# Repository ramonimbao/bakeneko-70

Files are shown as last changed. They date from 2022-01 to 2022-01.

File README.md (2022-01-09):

# Bakeneko 70 V1

A 70% keyboard based on the Bakeneko 60 by kkatano.

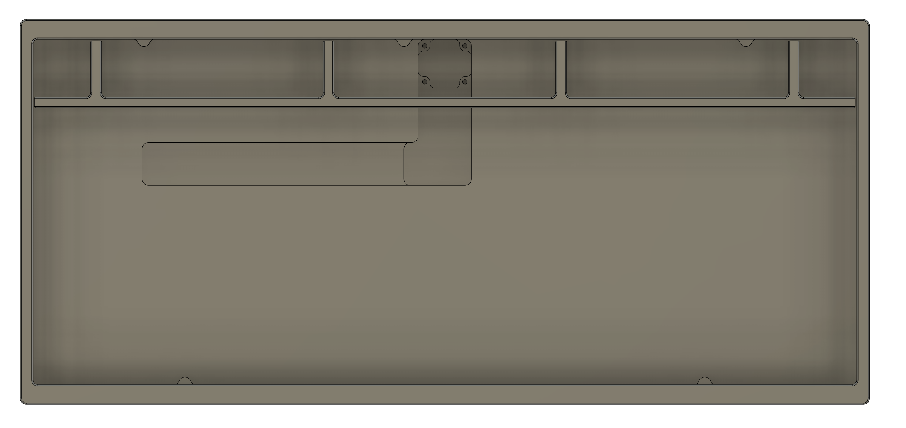
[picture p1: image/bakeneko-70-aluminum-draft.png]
Bakeneko 70


## Notes

Since this was based off of the Bakeneko 60, please take note that some files might still be named as bakeneko-60 or such. 

## Layouts

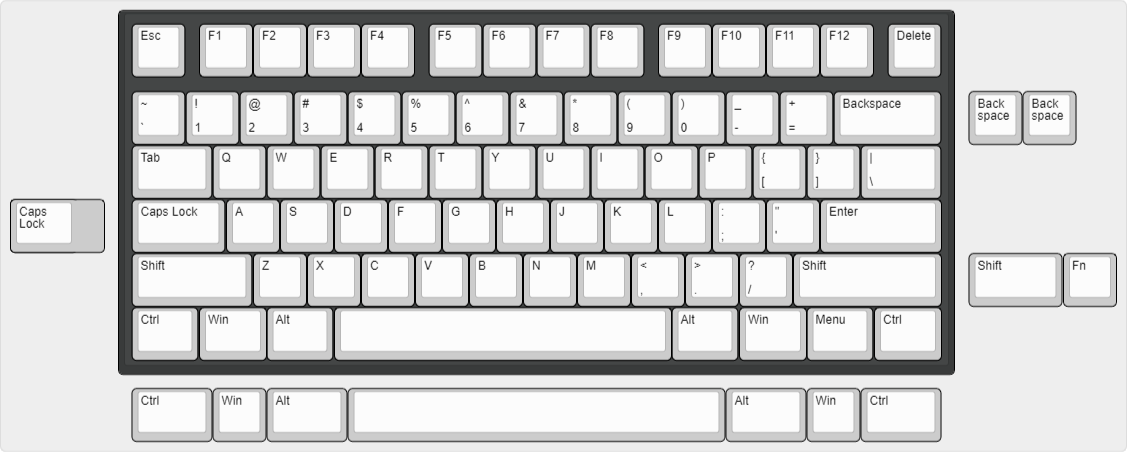
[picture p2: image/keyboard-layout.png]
Bakeneko 70 layouts


---

# Bakeneko 60 V3

A simple 60% keyboard for DIYers. This project is a special homage to TGR x Singa UNIKORN 60 and OTD 356 Mini.

## Features

- Single piece tray case
- O-ring gasket mount (Friction fit)
- USB-C with [Unified Daughterboard](https://github.com/ai03-2725/Unified-Daughterboard)
- QMK firmware and VIA ready
- Compatible with common 60% plates

## Specs

- Dimensions: 295 x 110 x 30mm
- Front height: 18.5mm
- Home row height: 31mm(with GMK keycaps and bumpons)
- Typing angle: 6 degree
- Weight:
  - PLA Case: 370g
  - Aluminum Case: 700g
- O-ring gasket: VMQ-50(Silicone 50 duro) AS568-262

## Notes

- All files are to be used at your own risk
- As for stabilizers, only PCB snap ins are supported
- This open source version is not compatible with CannonKeys' Bakeneko

## Resources

- Documents: https://drive.google.com/drive/folders/1tddSihOS8Pgf1lTQOjHohYCl8efxXIeH
  - Parts guide and other useful information
  - Will be added and updated as needed
- Discord: https://discord.gg/fMY96TeEwV
  - Have fun with community members
  - Talk about Bakeneko builds and mods, and share your works
  - You can also contact me from there

## Special thanks to

- **Elaine** for [Unikorn](https://geekhack.org/index.php?topic=98587.50). Allowed me to publish the Unikorn-inspired case as open source and encouraged me
- Of course, I also show my respect and gratitude to **yuktsi**
- **coarse** for PCB review and kind support. His great work has refined the PCB well

## Also I should mention

- **OTD** for 356 Mini. Origin of O-ring gasket mount style
- **Evy** for [Plain60 series](https://github.com/evyd13/plain60-c). I used it as a reference for my PCB design. They also answered my miscellaneous questions
- **ai03** for [MX_Alps_Hybrid](https://github.com/ai03-2725/MX_Alps_Hybrid) and [random-keyboard-parts.pretty](https://github.com/ai03-2725/random-keyboard-parts.pretty). Also got a lot of help from his discord server
- **overset** for [JP01](https://github.com/overset/JP01). The idea of publishing the case design on Onshape. After seeing their great work I switched from fusion360 to Onshape
- **Rhuk** gave me a lot of advice on keyboard design and manufacturing
- **Maker Keyboards** suggested adding a plate cutout to remove the PCB using a keycap puller
- And many community members for giving me advice and feedback, thanks!

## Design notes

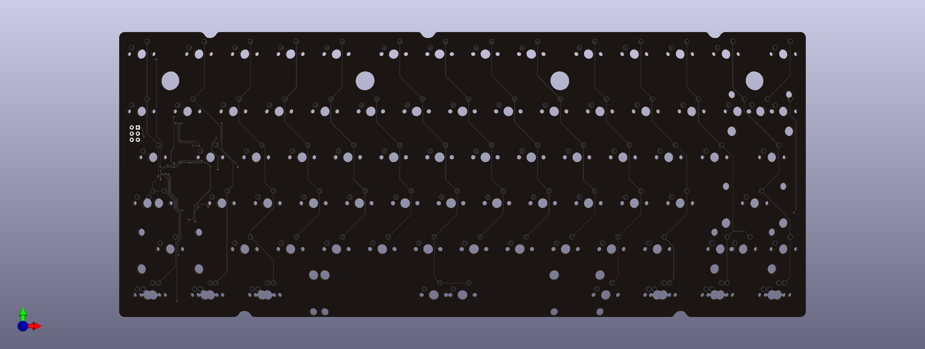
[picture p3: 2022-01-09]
image/bakeneko-70-pcb-top.png

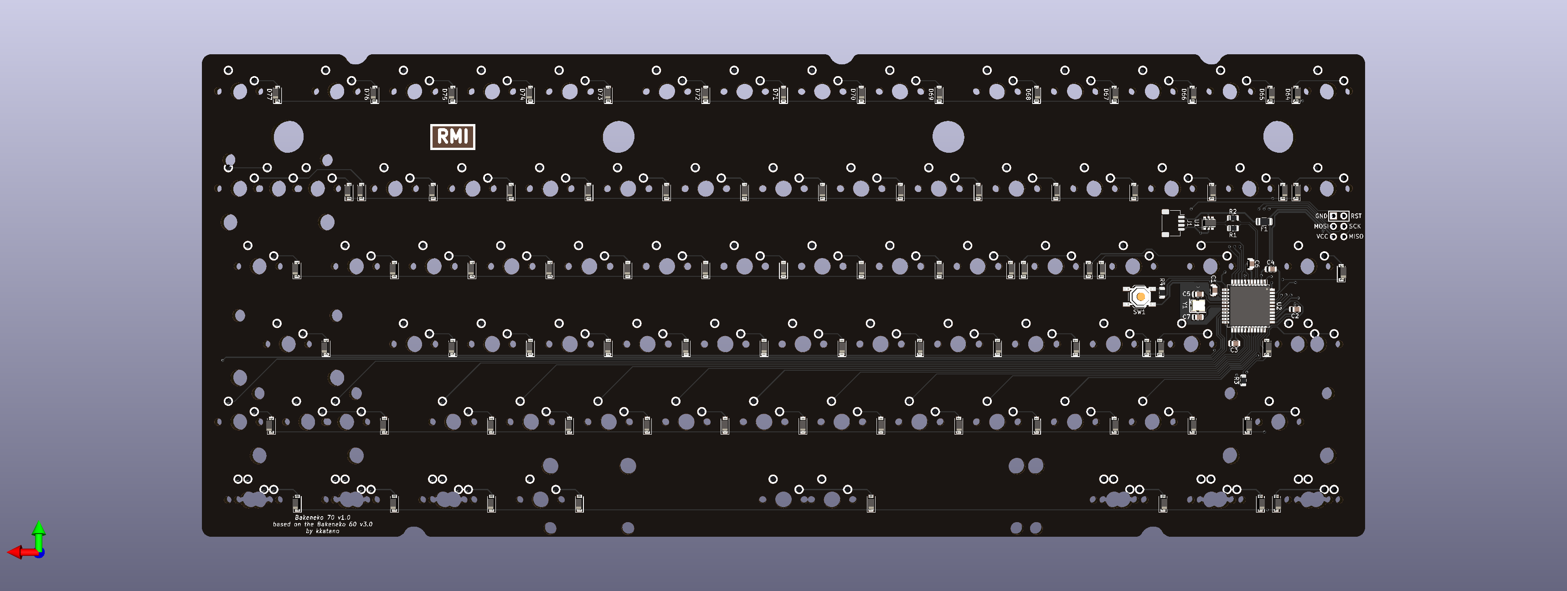
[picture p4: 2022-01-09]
image/bakeneko-70-pcb-bottom.png

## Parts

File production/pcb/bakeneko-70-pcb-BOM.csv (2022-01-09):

Comment | Designator | Footprint | LCSC
0.1u | C1,C2,C3 | Capacitor_SMD:C_0805_2012Metric
10u | C4 | Capacitor_SMD:C_0805_2012Metric
22p | C5,C7 | Capacitor_SMD:C_0805_2012Metric
1u | C6 | Capacitor_SMD:C_0805_2012Metric
1N4148 | D1,D2,D3,D4,D5,D6,D7,D8,D9,D10,D11,D12,D13,D14,D15,D16,D17,D18,D19,D20,D21,D22,D23,D24,D25,D26,D27,D28,D29,D30,D31,D32,D33,D34,D35,D36,D37,D38,D39,D40,D41,D42,D43,D44,D45,D46,D47,D48,D49,D50,D51,D52,D53,D54,D55,D56,D57,D58,D59,D60,D61,D62,D63,D64,D65,D66,D67,D68,D69,D70,D71,D72,D73,D74,D75,D76,D77 | Diode_SMD:D_SOD-123
500mA | F1 | Fuse:Fuse_1206_3216Metric
Signature | G1 | Ramon:Signature
JST SH 4-pin | J1 | Connector_JST:JST_SH_SM04B-SRSS-TB_1x04-1MP_P1.00mm_Horizontal
AVR-ISP-6 | J2 | random-keyboard-parts:Reset_Pretty
2u | MX16 | MX_Only:MXOnly-2U-NoLED
1.5u | MX17,MX30,MX67,MX69,MX71,MX73 | MX_Only:MXOnly-1.5U-NoLED
1.25u | MX31,MX59,MX60,MX61,MX63,MX64,MX65,MX66 | MX_Only:MXOnly-1.25U-NoLED
1.75u | MX32,MX56 | MX_Only:MXOnly-1.75U-NoLED
2.25u | MX44,MX45 | MX_Only:MXOnly-2.25U-NoLED
1u | MX1,MX2,MX3,MX4,MX5,MX6,MX7,MX8,MX9,MX10,MX11,MX12,MX13,MX14,MX15,MX18,MX19,MX20,MX21,MX22,MX23,MX24,MX25,MX26,MX27,MX28,MX29,MX33,MX34,MX35,MX36,MX37,MX38,MX39,MX40,MX41,MX42,MX43,MX46,MX47,MX48,MX49,MX50,MX51,MX52,MX53,MX54,MX55,MX57,MX68,MX72,MX74,MX75,MX76,MX77,MX78,MX79,MX80,MX81,MX82,MX83,MX84,MX85,MX86,MX87 | MX_Only:MXOnly-1U-NoLED
2.75u | MX58 | MX_Only:MXOnly-2.75U-NoLED
6.25u | MX62 | MX_Only:MXOnly-6.25U-ReversedStabilizers-NoLED
7u | MX70 | MX_Only:MXOnly-7U-ReversedStabilizers-NoLED
22 | R1,R2 | Resistor_SMD:R_0805_2012Metric
10k | R3,R4 | Resistor_SMD:R_0805_2012Metric
Reset | SW1 | Button_Switch_SMD:SW_SPST_TL3342
SRV05-4 | U1 | Package_TO_SOT_SMD:SOT-23-6
ATmega32U4-AU | U2 | Package_QFP:TQFP-44_10x10mm_P0.8mm
16MHz | Y1 | Crystal:Crystal_SMD_3225-4Pin_3.2x2.5mm

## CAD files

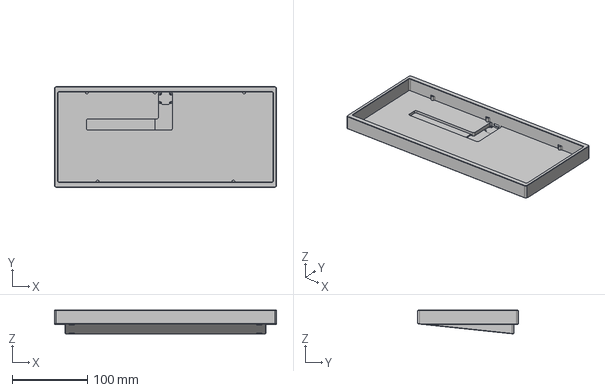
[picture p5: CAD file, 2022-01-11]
case/Case.step
295.7 x 134.0 x 31.9 mm

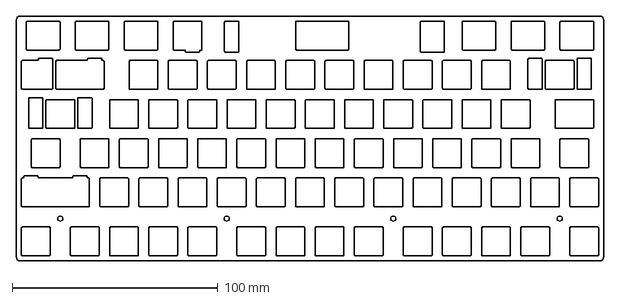
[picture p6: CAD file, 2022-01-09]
plate/bakeneko70-plate/bakeneko70-plate.dxf
285.8 x 119.1 mm

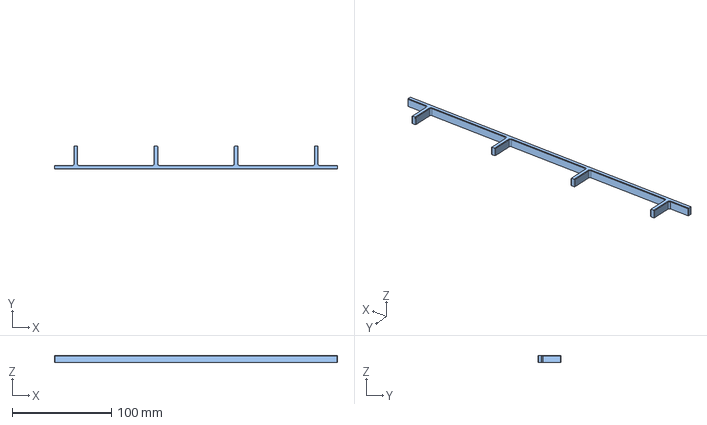
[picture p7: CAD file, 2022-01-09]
case/Blockers.step
285.8 x 23.3 x 7.00 mm

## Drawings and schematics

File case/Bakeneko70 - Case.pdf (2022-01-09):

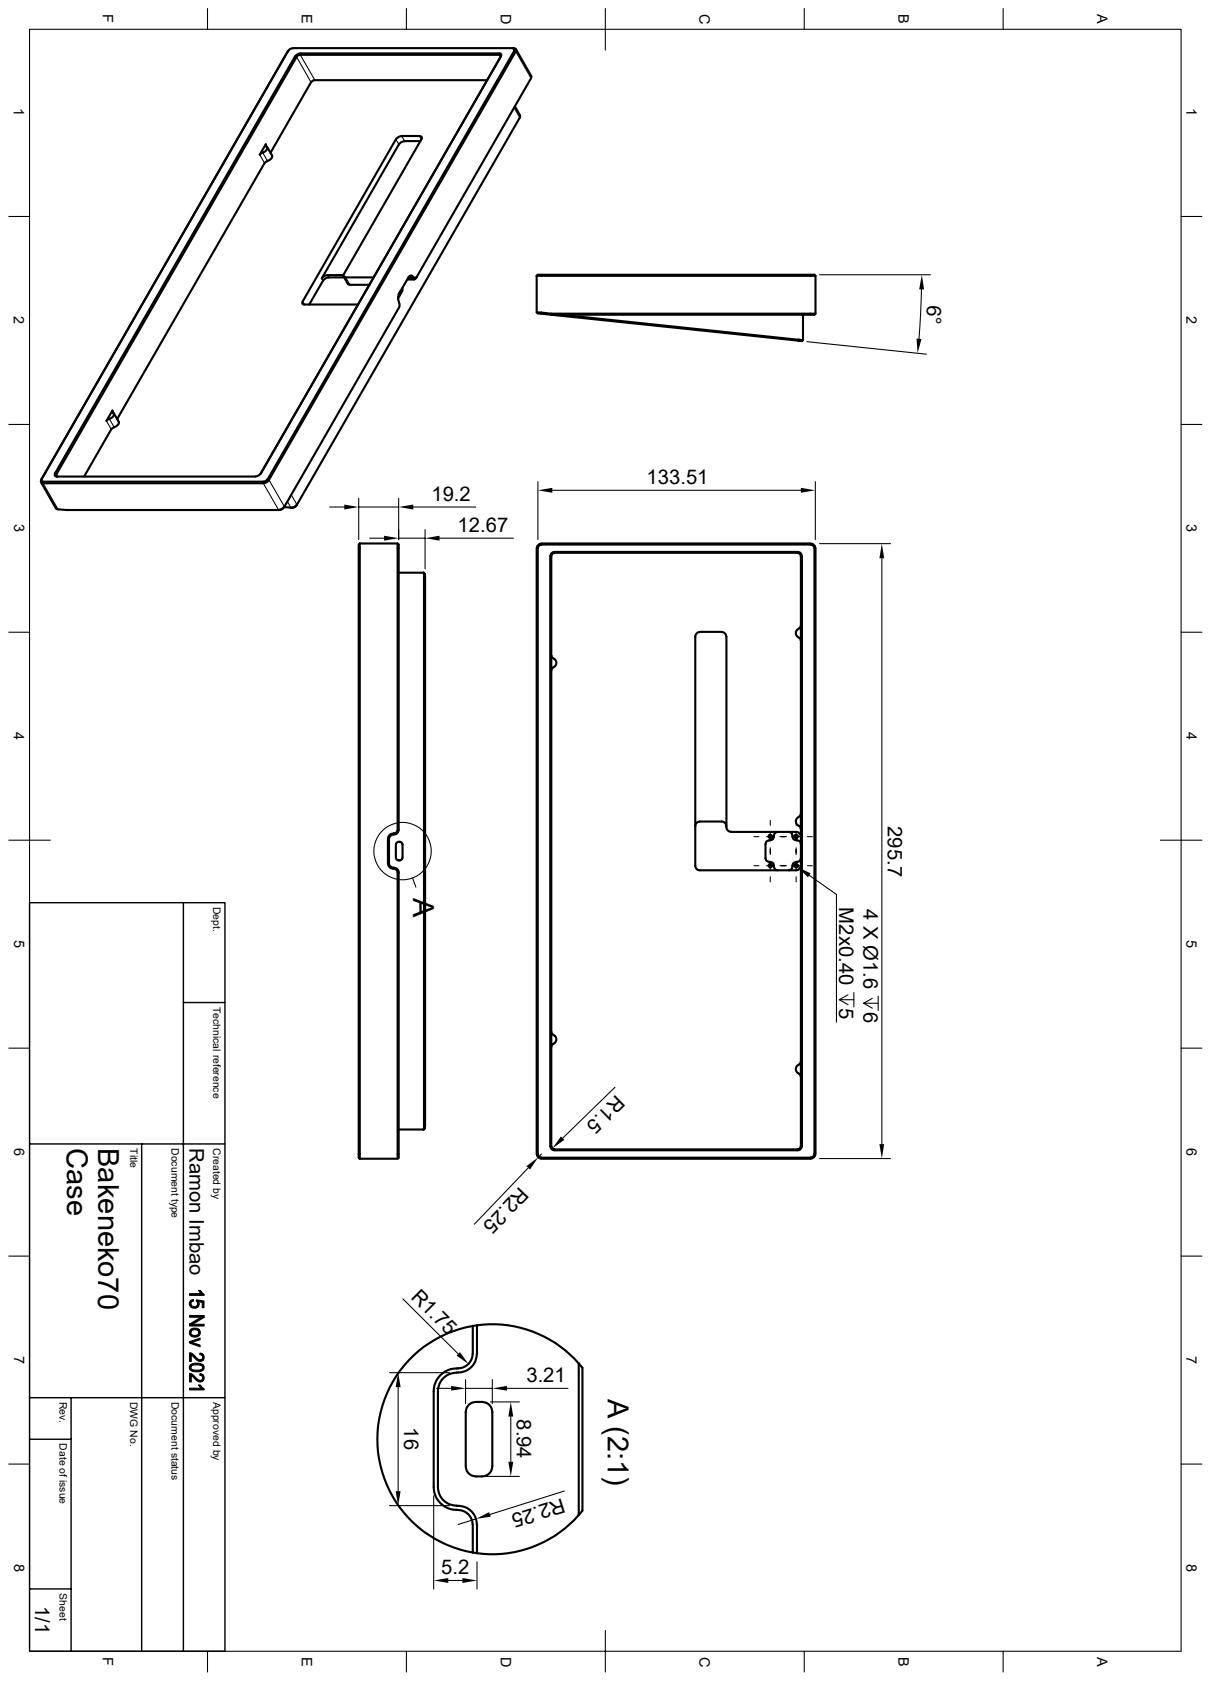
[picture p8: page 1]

1 A 2 3 4 5 6 7 8 1 2 3 4 5 6 7 8 FEDCB FEDCBA Dept. Technical reference Created by Approved by Title DWG No. Document type Document status Rev. Date of issue Sheet 1/1 Case Bakeneko70 Ramon Imbao 6° 295.7

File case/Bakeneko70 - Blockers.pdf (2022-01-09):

23.31 7

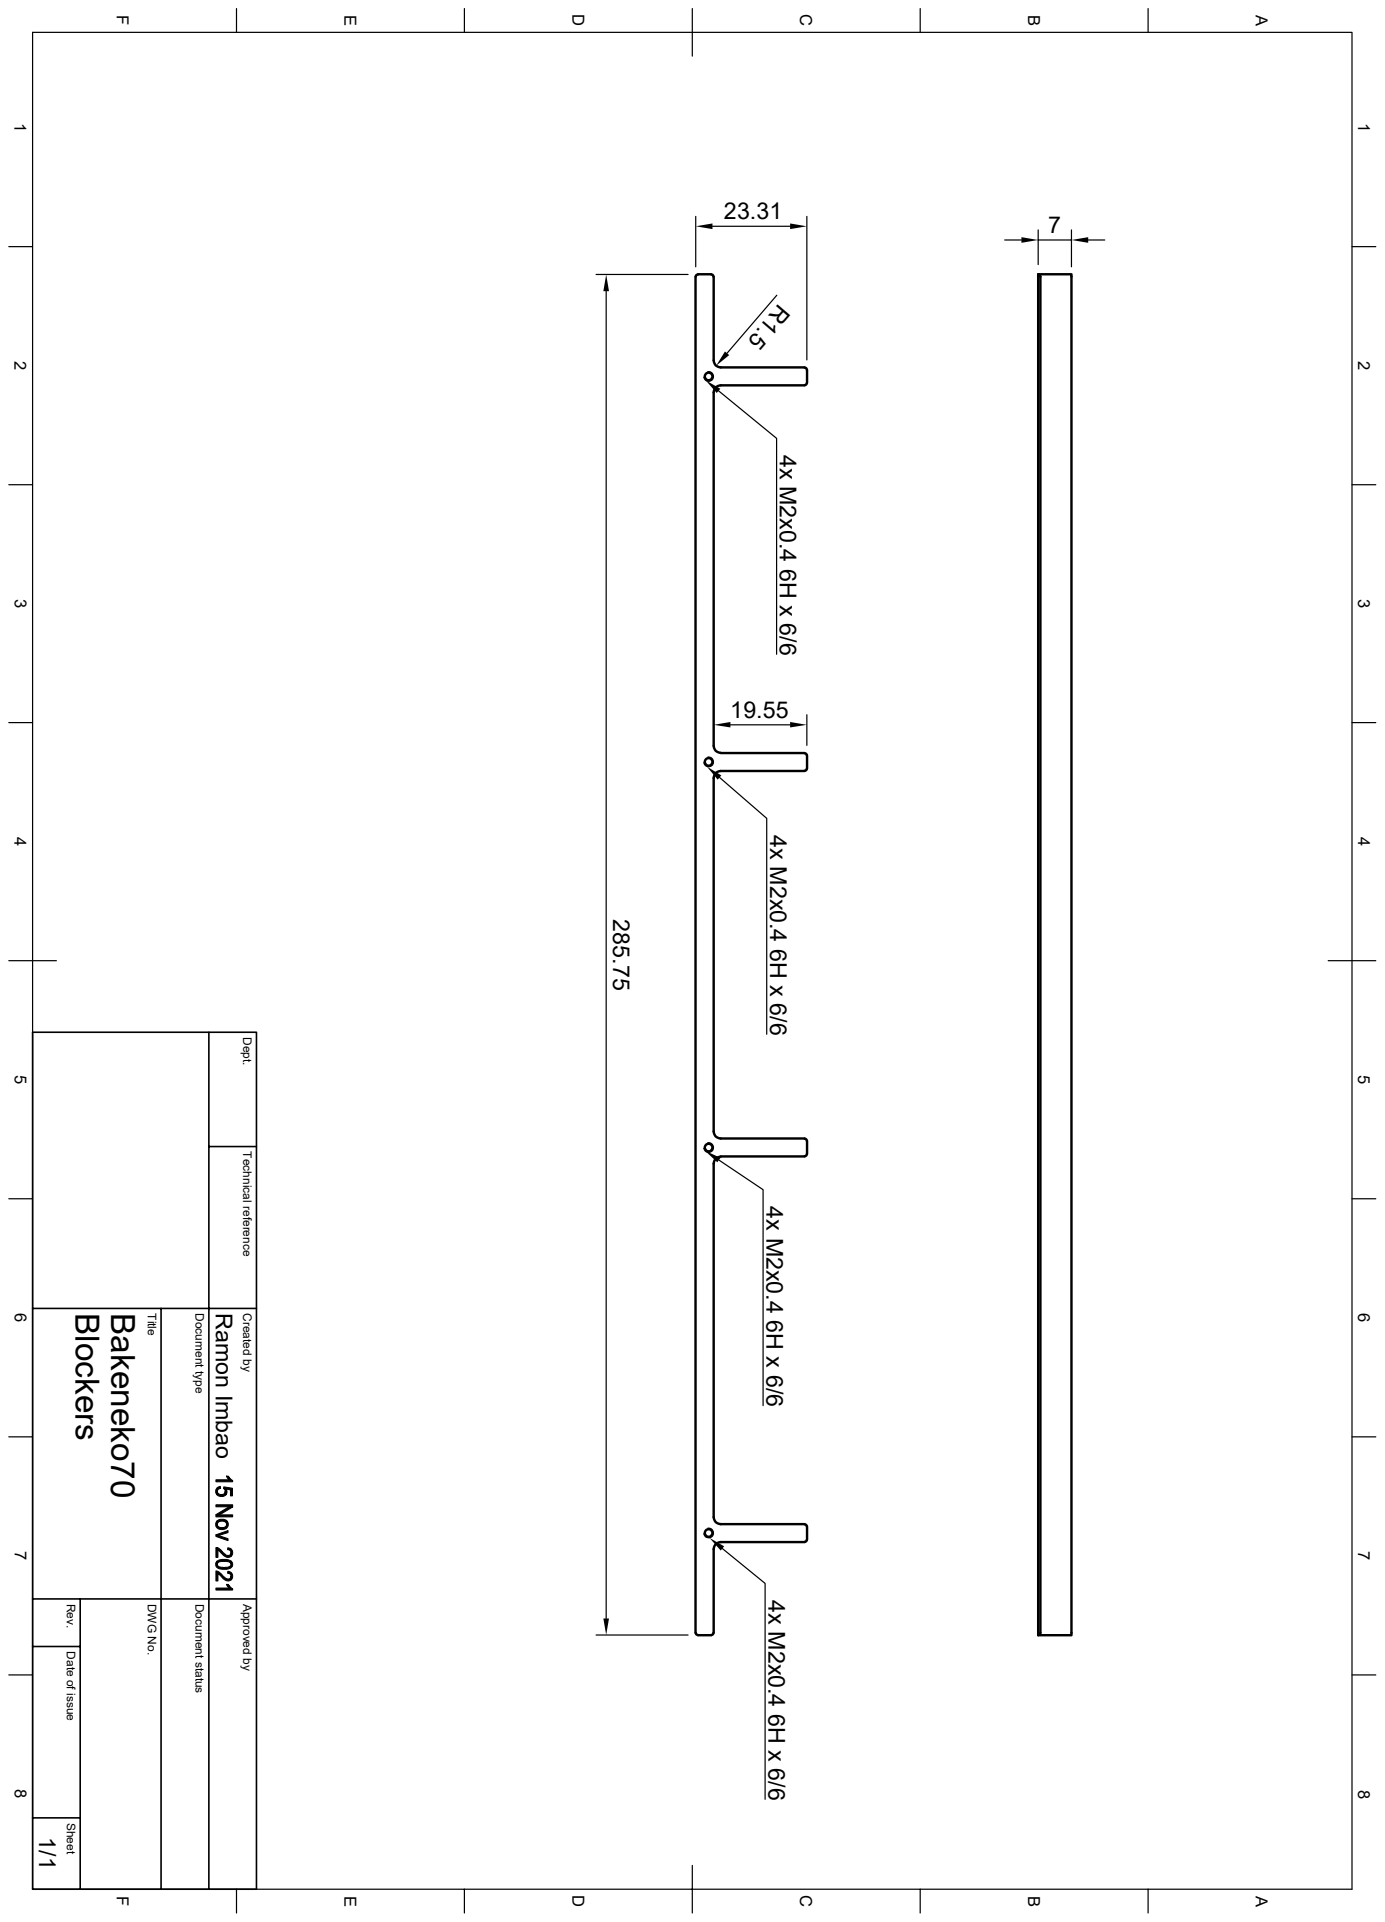
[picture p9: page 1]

1 A 2 3 4 5 6 7 8 1 2 3 4 5 6 7 8 FEDCB FEDCBA Dept. Technical reference Created by Approved by Title DWG No. Document type Document status Rev. Date of issue Sheet 1/1 Blockers Bakeneko70 Ramon Imbao 4x M2x0.4 6H x 6/6 4x M2x0.4 6H x 6/6 4x M2x0.4 6H x 6/6 4x M2x0.4 6H x 6/6 R1.5

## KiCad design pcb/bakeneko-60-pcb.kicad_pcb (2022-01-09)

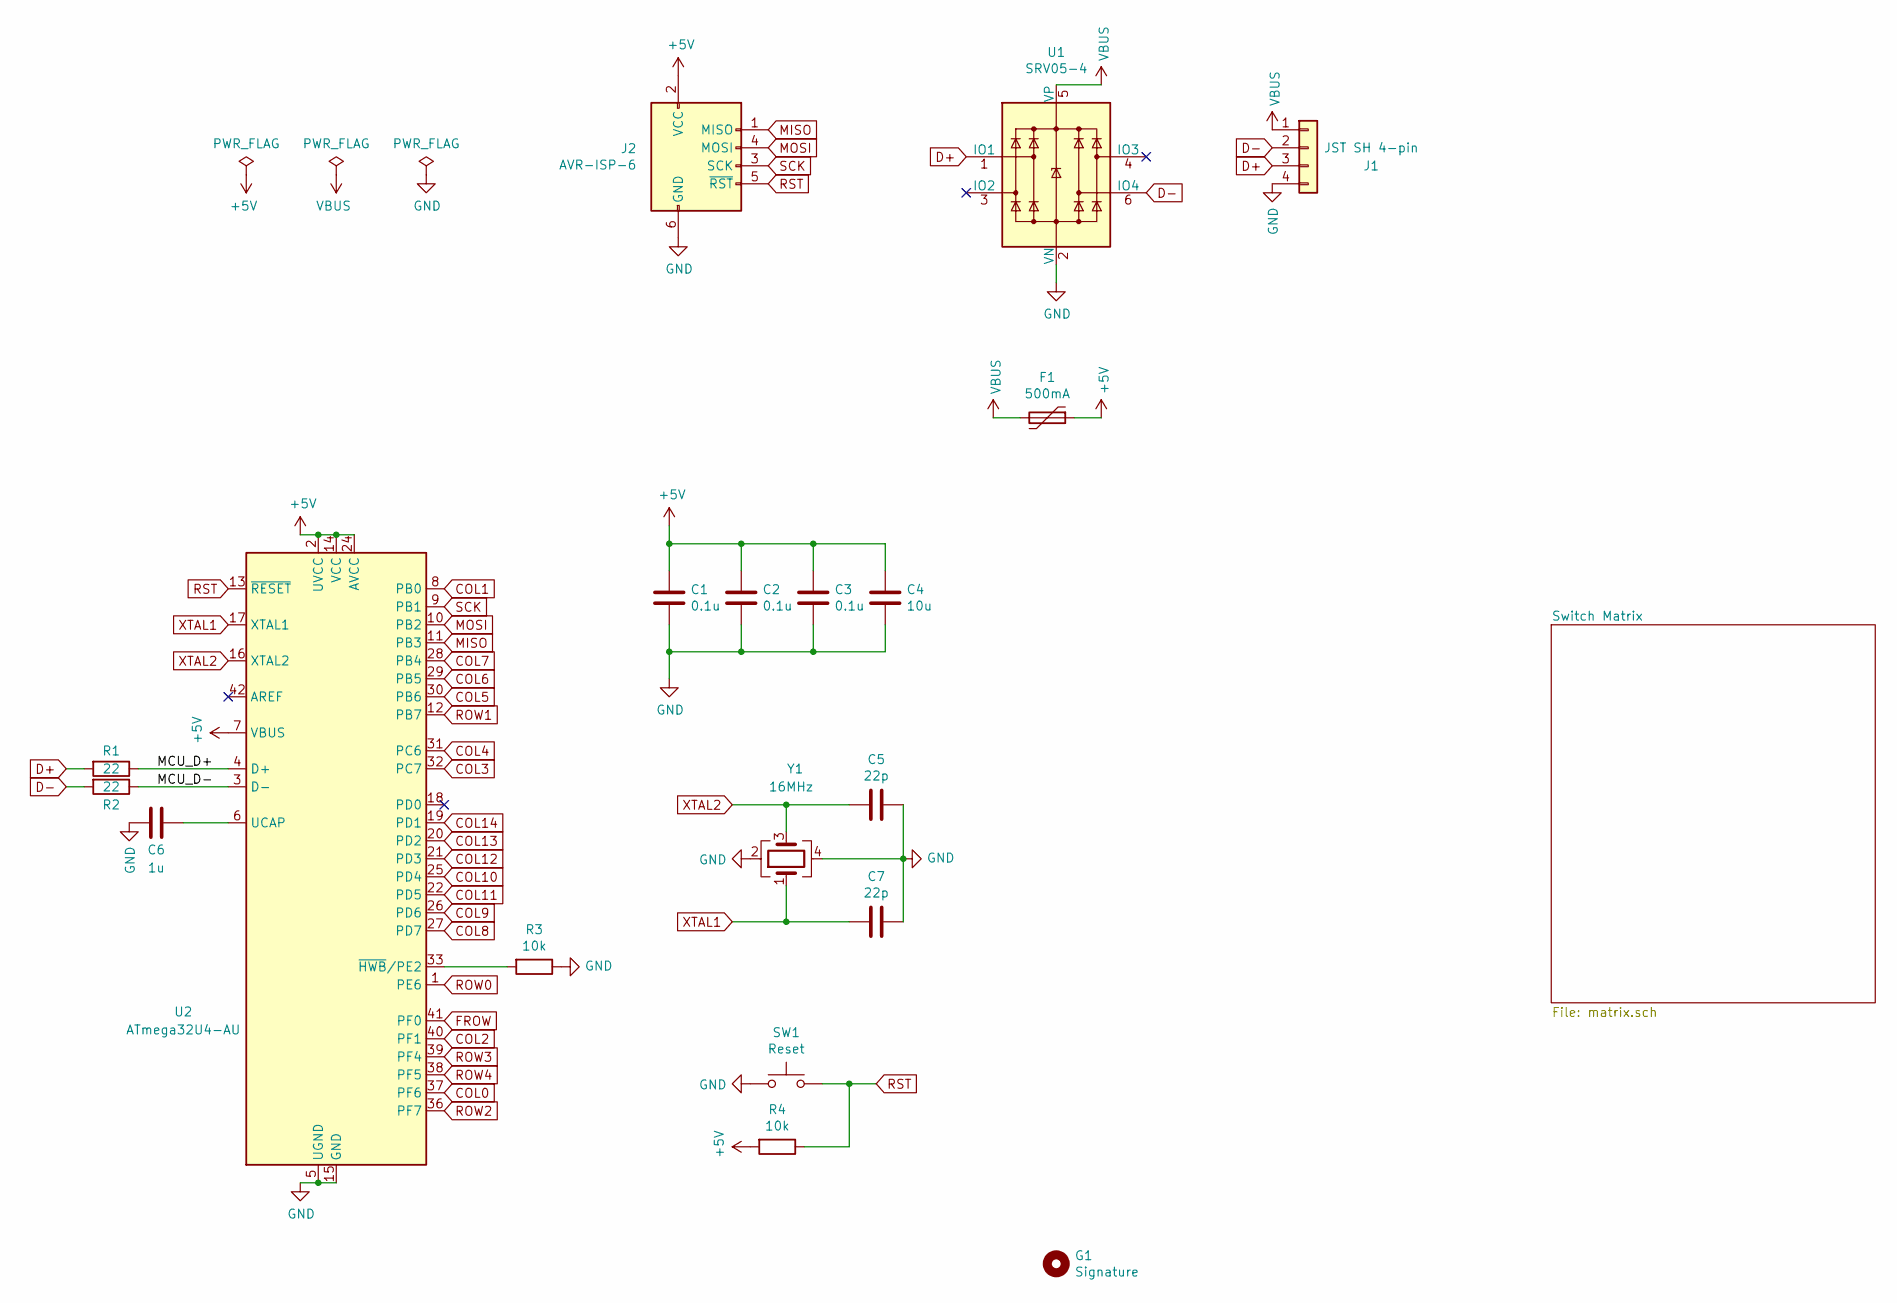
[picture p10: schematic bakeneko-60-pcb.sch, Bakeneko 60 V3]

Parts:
C1, C2, C3: 0.1u; C_0805_2012Metric; LCSC Part # C49678
C4: 10u; C_0805_2012Metric; LCSC Part # C15850
C5, C7: 22p; C_0805_2012Metric; LCSC Part # C1804
C6: 1u; C_0805_2012Metric; LCSC Part # C28323
F1: 500mA; Fuse_1206_3216Metric; LCSC Part # C70076
G1: Signature
J1: JST SH 4-pin; JST_SH_SM04B-SRSS-TB_1x04-1MP_P1.00mm_Horizontal; LCSC Part # C160404
J2: AVR-ISP-6; Reset_Pretty
R1, R2: 22; R_0805_2012Metric; LCSC Part # C17561
R3, R4: 10k; R_0805_2012Metric; LCSC Part # C17414
SW1: Reset; SW_SPST_TL3342; LCSC Part # C318884
U1: SRV05-4; SOT-23-6; LCSC Part # C85364
U2: ATmega32U4-AU; TQFP-44_10x10mm_P0.8mm; LCSC Part # C44854
Y1: 16MHz; Crystal_SMD_3225-4Pin_3.2x2.5mm; LCSC Part # C13738

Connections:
+5V: C1.1, C2.1, C3.1, C4.1, F1.1, J2.2 (VCC), R4.2, U2.2 (UVCC), U2.7 (VBUS), U2.14 (VCC), U2.24 (AVCC), U2.34 (VCC), U2.44 (AVCC)
/MCU_D+: R1.1, U2.4 (D+)
/MCU_D-: R2.1, U2.3 (D-)
COL0: U2.37 (PF6); also elsewhere on the board
COL1: U2.8 (PB0); also elsewhere on the board
COL2: U2.40 (PF1); also elsewhere on the board
COL3: U2.32 (PC7); also elsewhere on the board
COL4: U2.31 (PC6); also elsewhere on the board
COL5: U2.30 (PB6); also elsewhere on the board
COL6: U2.29 (PB5); also elsewhere on the board
COL7: U2.28 (PB4); also elsewhere on the board
COL8: U2.27 (PD7); also elsewhere on the board
COL9: U2.26 (PD6); also elsewhere on the board
COL10: U2.25 (PD4); also elsewhere on the board
COL11: U2.22 (PD5); also elsewhere on the board
COL12: U2.21 (PD3); also elsewhere on the board
COL13: U2.20 (PD2); also elsewhere on the board
COL14: U2.19 (PD1); also elsewhere on the board
D+: J1.3, R1.2, U1.1 (IO1)
D-: J1.2, R2.2, U1.6 (IO4)
FROW: U2.41 (PF0); also elsewhere on the board
GND: C1.2, C2.2, C3.2, C4.2, C5.1, C6.2, C7.1, J1.4, J2.6 (GND), R3.1, SW1.1, U1.2 (VN), U2.5 (UGND), U2.15 (GND), U2.23 (GND), U2.35 (GND), U2.43 (GND), Y1.2, Y1.4
MISO: J2.1 (MISO), U2.11 (PB3)
MOSI: J2.4 (MOSI), U2.10 (PB2)
unnamed: C6.1, U2.6 (UCAP)
unnamed: R3.2, U2.33 (~HWB~/PE2)
ROW0: U2.1 (PE6); also elsewhere on the board
ROW1: U2.12 (PB7); also elsewhere on the board
ROW2: U2.36 (PF7); also elsewhere on the board
ROW3: U2.39 (PF4); also elsewhere on the board
ROW4: U2.38 (PF5); also elsewhere on the board
RST: J2.5 (~RST), R4.1, SW1.2, U2.13 (~RESET)
SCK: J2.3 (SCK), U2.9 (PB1)
VBUS: F1.2, J1.1, U1.5 (VP)
XTAL1: C7.2, U2.17 (XTAL1), Y1.1
XTAL2: C5.2, U2.16 (XTAL2), Y1.3

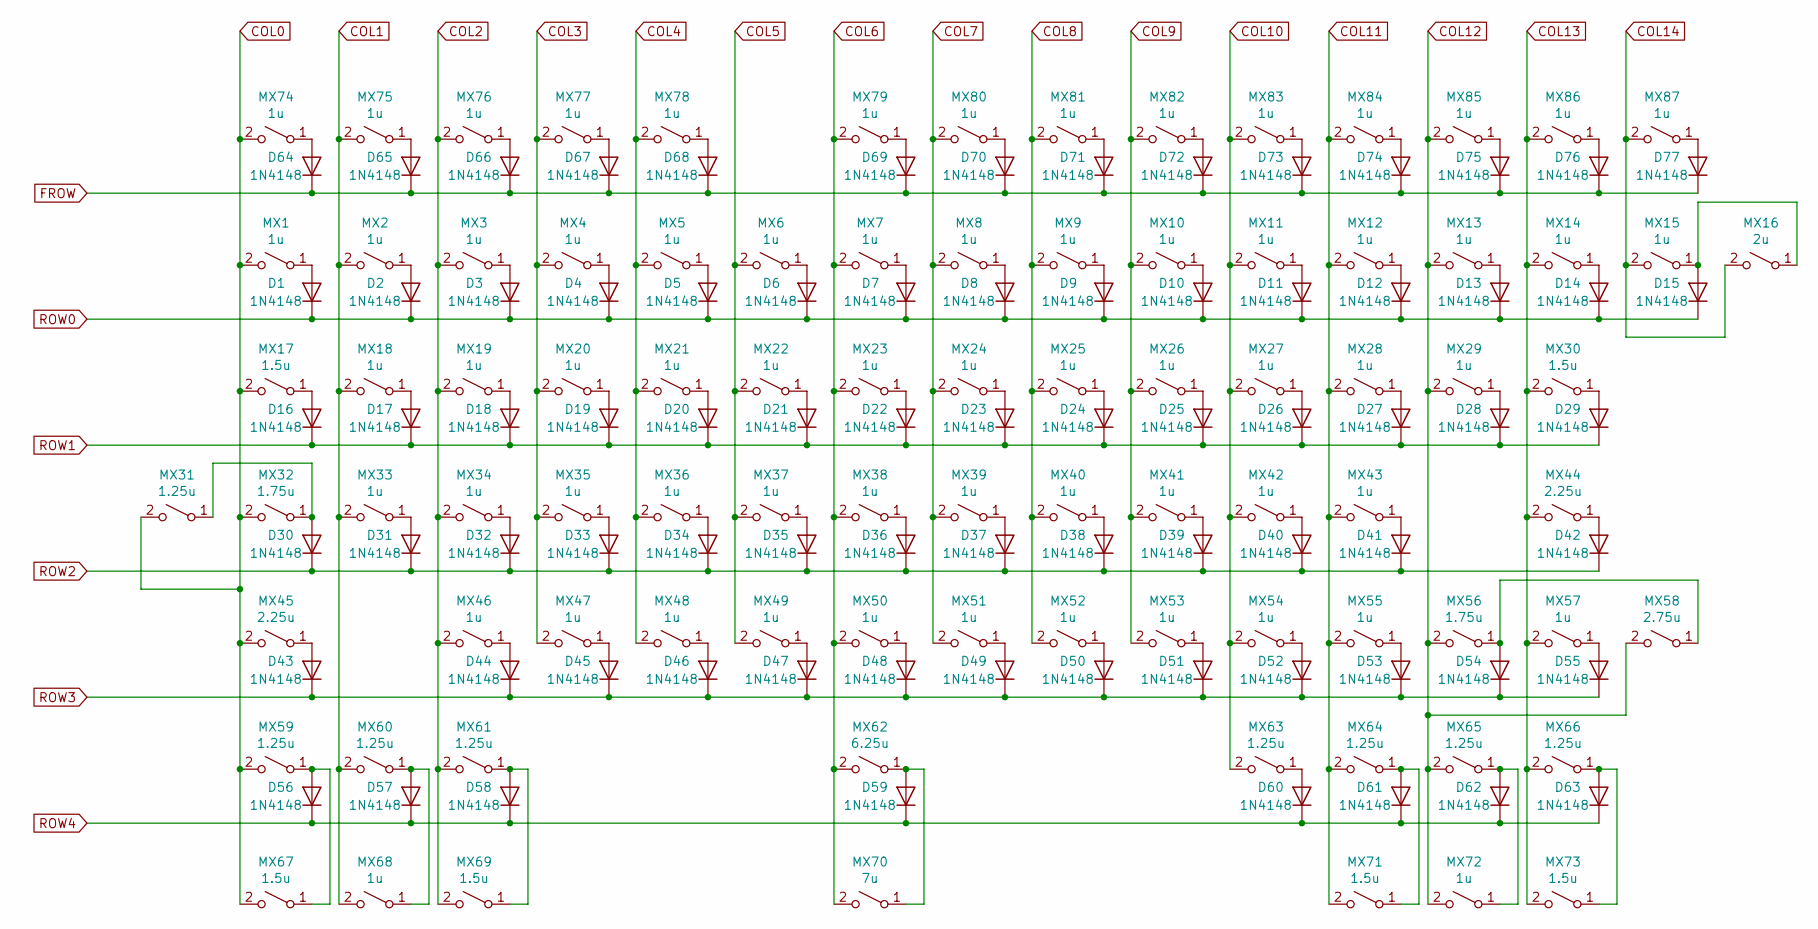
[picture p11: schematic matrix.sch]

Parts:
D1, D2, D3, D4, D5, D6, D7, D8, D9, D10, D11, D12, D13, D14, D15, D16, D17, D18, D19, D20, D21, D22, D23, D24, D25, D26, D27, D28, D29, D30, D31, D32, D33, D34, D35, D36, D37, D38, D39, D40, D41, D42, D43, D44, D45, D46, D47, D48, D49, D50, D51, D52, D53, D54, D55, D56, D57, D58, D59, D60, D61, D62, D63, D64, D65, D66, D67, D68, D69, D70, D71, D72, D73, D74, D75, D76, D77: 1N4148; D_SOD-123; LCSC Part # C81598
MX1, MX2, MX3, MX4, MX5, MX6, MX7, MX8, MX9, MX10, MX11, MX12, MX13, MX14, MX15, MX18, MX19, MX20, MX21, MX22, MX23, MX24, MX25, MX26, MX27, MX28, MX29, MX33, MX34, MX35, MX36, MX37, MX38, MX39, MX40, MX41, MX42, MX43, MX46, MX47, MX48, MX49, MX50, MX51, MX52, MX53, MX54, MX55, MX57, MX68, MX72, MX74, MX75, MX76, MX77, MX78, MX79, MX80, MX81, MX82, MX83, MX84, MX85, MX86, MX87: 1u; MXOnly-1U-NoLED
MX16: 2u; MXOnly-2U-NoLED
MX17, MX30, MX67, MX69, MX71, MX73: 1.5u; MXOnly-1.5U-NoLED
MX31, MX59, MX60, MX61, MX63, MX64, MX65, MX66: 1.25u; MXOnly-1.25U-NoLED
MX32, MX56: 1.75u; MXOnly-1.75U-NoLED
MX44, MX45: 2.25u; MXOnly-2.25U-NoLED
MX58: 2.75u; MXOnly-2.75U-NoLED
MX62: 6.25u; MXOnly-6.25U-ReversedStabilizers-NoLED
MX70: 7u; MXOnly-7U-ReversedStabilizers-NoLED

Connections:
COL0: MX1.2 (B), MX17.2 (B), MX31.2 (B), MX32.2 (B), MX45.2 (B), MX59.2 (B), MX67.2 (B), MX74.2 (B); also elsewhere on the board
COL1: MX2.2 (B), MX18.2 (B), MX33.2 (B), MX60.2 (B), MX68.2 (B), MX75.2 (B); also elsewhere on the board
COL2: MX3.2 (B), MX19.2 (B), MX34.2 (B), MX46.2 (B), MX61.2 (B), MX69.2 (B), MX76.2 (B); also elsewhere on the board
COL3: MX4.2 (B), MX20.2 (B), MX35.2 (B), MX47.2 (B), MX77.2 (B); also elsewhere on the board
COL4: MX5.2 (B), MX21.2 (B), MX36.2 (B), MX48.2 (B), MX78.2 (B); also elsewhere on the board
COL5: MX6.2 (B), MX22.2 (B), MX37.2 (B), MX49.2 (B); also elsewhere on the board
COL6: MX7.2 (B), MX23.2 (B), MX38.2 (B), MX50.2 (B), MX62.2 (B), MX70.2 (B), MX79.2 (B); also elsewhere on the board
COL7: MX8.2 (B), MX24.2 (B), MX39.2 (B), MX51.2 (B), MX80.2 (B); also elsewhere on the board
COL8: MX9.2 (B), MX25.2 (B), MX40.2 (B), MX52.2 (B), MX81.2 (B); also elsewhere on the board
COL9: MX10.2 (B), MX26.2 (B), MX41.2 (B), MX53.2 (B), MX82.2 (B); also elsewhere on the board
COL10: MX11.2 (B), MX27.2 (B), MX42.2 (B), MX54.2 (B), MX63.2 (B), MX83.2 (B); also elsewhere on the board
COL11: MX12.2 (B), MX28.2 (B), MX43.2 (B), MX55.2 (B), MX64.2 (B), MX71.2 (B), MX84.2 (B); also elsewhere on the board
COL12: MX13.2 (B), MX29.2 (B), MX56.2 (B), MX58.2 (B), MX65.2 (B), MX72.2 (B), MX85.2 (B); also elsewhere on the board
COL13: MX14.2 (B), MX30.2 (B), MX44.2 (B), MX57.2 (B), MX66.2 (B), MX73.2 (B), MX86.2 (B); also elsewhere on the board
COL14: MX15.2 (B), MX16.2 (B), MX87.2 (B); also elsewhere on the board
FROW: D64.1 (K), D65.1 (K), D66.1 (K), D67.1 (K), D68.1 (K), D69.1 (K), D70.1 (K), D71.1 (K), D72.1 (K), D73.1 (K), D74.1 (K), D75.1 (K), D76.1 (K), D77.1 (K); also elsewhere on the board
unnamed: D1.2 (A), MX1.1 (A)
unnamed: D2.2 (A), MX2.1 (A)
unnamed: D3.2 (A), MX3.1 (A)
unnamed: D4.2 (A), MX4.1 (A)
unnamed: D5.2 (A), MX5.1 (A)
unnamed: D6.2 (A), MX6.1 (A)
unnamed: D7.2 (A), MX7.1 (A)
unnamed: D8.2 (A), MX8.1 (A)
unnamed: D9.2 (A), MX9.1 (A)
unnamed: D10.2 (A), MX10.1 (A)
unnamed: D11.2 (A), MX11.1 (A)
unnamed: D12.2 (A), MX12.1 (A)
unnamed: D13.2 (A), MX13.1 (A)
unnamed: D14.2 (A), MX14.1 (A)
unnamed: D15.2 (A), MX15.1 (A), MX16.1 (A)
unnamed: D16.2 (A), MX17.1 (A)
unnamed: D17.2 (A), MX18.1 (A)
unnamed: D18.2 (A), MX19.1 (A)
unnamed: D19.2 (A), MX20.1 (A)
unnamed: D20.2 (A), MX21.1 (A)
unnamed: D21.2 (A), MX22.1 (A)
unnamed: D22.2 (A), MX23.1 (A)
unnamed: D23.2 (A), MX24.1 (A)
unnamed: D24.2 (A), MX25.1 (A)
unnamed: D25.2 (A), MX26.1 (A)
unnamed: D26.2 (A), MX27.1 (A)
unnamed: D27.2 (A), MX28.1 (A)
unnamed: D28.2 (A), MX29.1 (A)
unnamed: D29.2 (A), MX30.1 (A)
unnamed: D30.2 (A), MX31.1 (A), MX32.1 (A)
unnamed: D31.2 (A), MX33.1 (A)
unnamed: D32.2 (A), MX34.1 (A)
unnamed: D33.2 (A), MX35.1 (A)
unnamed: D34.2 (A), MX36.1 (A)
unnamed: D35.2 (A), MX37.1 (A)
unnamed: D36.2 (A), MX38.1 (A)
unnamed: D37.2 (A), MX39.1 (A)
unnamed: D38.2 (A), MX40.1 (A)
unnamed: D39.2 (A), MX41.1 (A)
unnamed: D40.2 (A), MX42.1 (A)
unnamed: D41.2 (A), MX43.1 (A)
unnamed: D42.2 (A), MX44.1 (A)
unnamed: D43.2 (A), MX45.1 (A)
unnamed: D44.2 (A), MX46.1 (A)
unnamed: D45.2 (A), MX47.1 (A)
unnamed: D46.2 (A), MX48.1 (A)
unnamed: D47.2 (A), MX49.1 (A)
unnamed: D48.2 (A), MX50.1 (A)
unnamed: D49.2 (A), MX51.1 (A)
unnamed: D50.2 (A), MX52.1 (A)
unnamed: D51.2 (A), MX53.1 (A)
unnamed: D52.2 (A), MX54.1 (A)
unnamed: D53.2 (A), MX55.1 (A)
unnamed: D54.2 (A), MX56.1 (A), MX58.1 (A)
unnamed: D55.2 (A), MX57.1 (A)
unnamed: D56.2 (A), MX59.1 (A), MX67.1 (A)
unnamed: D57.2 (A), MX60.1 (A), MX68.1 (A)
unnamed: D58.2 (A), MX61.1 (A), MX69.1 (A)
unnamed: D59.2 (A), MX62.1 (A), MX70.1 (A)
unnamed: D60.2 (A), MX63.1 (A)
unnamed: D61.2 (A), MX64.1 (A), MX71.1 (A)
unnamed: D62.2 (A), MX65.1 (A), MX72.1 (A)
unnamed: D63.2 (A), MX66.1 (A), MX73.1 (A)
unnamed: D64.2 (A), MX74.1 (A)
unnamed: D65.2 (A), MX75.1 (A)
unnamed: D66.2 (A), MX76.1 (A)
unnamed: D67.2 (A), MX77.1 (A)
unnamed: D68.2 (A), MX78.1 (A)
unnamed: D69.2 (A), MX79.1 (A)
unnamed: D70.2 (A), MX80.1 (A)
unnamed: D71.2 (A), MX81.1 (A)
unnamed: D72.2 (A), MX82.1 (A)
unnamed: D73.2 (A), MX83.1 (A)
unnamed: D74.2 (A), MX84.1 (A)
unnamed: D75.2 (A), MX85.1 (A)
unnamed: D76.2 (A), MX86.1 (A)
unnamed: D77.2 (A), MX87.1 (A)
ROW0: D1.1 (K), D2.1 (K), D3.1 (K), D4.1 (K), D5.1 (K), D6.1 (K), D7.1 (K), D8.1 (K), D9.1 (K), D10.1 (K), D11.1 (K), D12.1 (K), D13.1 (K), D14.1 (K), D15.1 (K); also elsewhere on the board
ROW1: D16.1 (K), D17.1 (K), D18.1 (K), D19.1 (K), D20.1 (K), D21.1 (K), D22.1 (K), D23.1 (K), D24.1 (K), D25.1 (K), D26.1 (K), D27.1 (K), D28.1 (K), D29.1 (K); also elsewhere on the board
ROW2: D30.1 (K), D31.1 (K), D32.1 (K), D33.1 (K), D34.1 (K), D35.1 (K), D36.1 (K), D37.1 (K), D38.1 (K), D39.1 (K), D40.1 (K), D41.1 (K), D42.1 (K); also elsewhere on the board
ROW3: D43.1 (K), D44.1 (K), D45.1 (K), D46.1 (K), D47.1 (K), D48.1 (K), D49.1 (K), D50.1 (K), D51.1 (K), D52.1 (K), D53.1 (K), D54.1 (K), D55.1 (K); also elsewhere on the board
ROW4: D56.1 (K), D57.1 (K), D58.1 (K), D59.1 (K), D60.1 (K), D61.1 (K), D62.1 (K), D63.1 (K); also elsewhere on the board

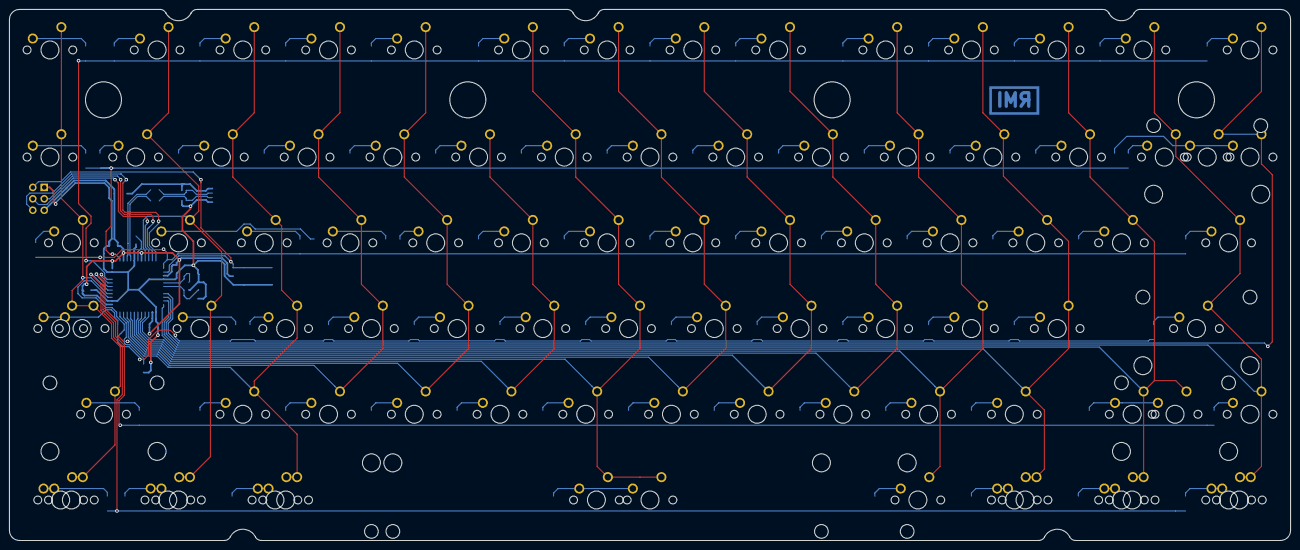
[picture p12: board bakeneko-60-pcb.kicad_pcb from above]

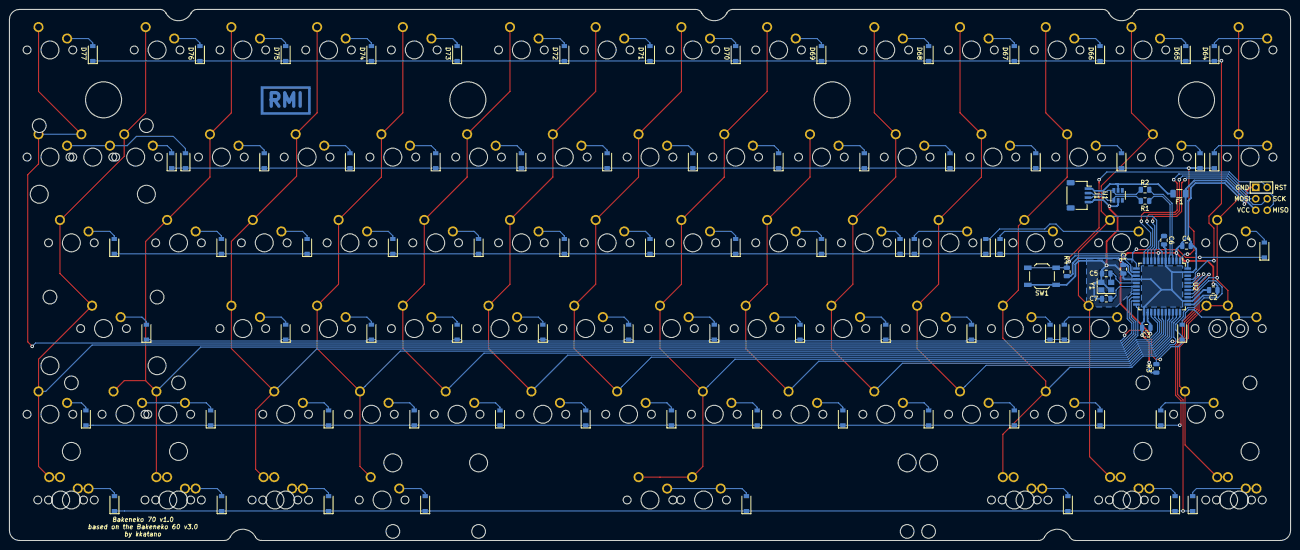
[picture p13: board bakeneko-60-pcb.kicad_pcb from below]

Board: 2 copper layers, 284.7 x 118.0 mm, 183 parts (96 on the bottom side), 113 nets.

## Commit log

2021-11-10 Bakeneko-70 intial implementation
    [bakeneko-60-pcb-B_Cu.gbl, bakeneko-60-pcb-B_Mask.gbs, bakeneko-60-pcb-B_Paste.gbp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]
2022-01-09 Add bakeneko 70 files
    [Blockers.step, Case.step, bakeneko-60-case.step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]
2022-01-11 Update case step file
    [Case.step]
